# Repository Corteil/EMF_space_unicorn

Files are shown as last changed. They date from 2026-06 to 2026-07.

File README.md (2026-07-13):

# 🦄 Space Unicorn — EMF 2026 Hexpansion

A WS2812 NeoPixel hexpansion for the EMF Tildagon badge. An ATtiny85 setup as an I²C client
drives the LEDs with animated patterns, predefined colour palettes and a user
button for live pattern cycling. Settings can be saved to the ATtiny85's
internal EEPROM so the badge lights up on its own, without the control app.
This repository holds the firmware and the KiCad hardware design.

| Front | Rear |
|:-----:|:----:|
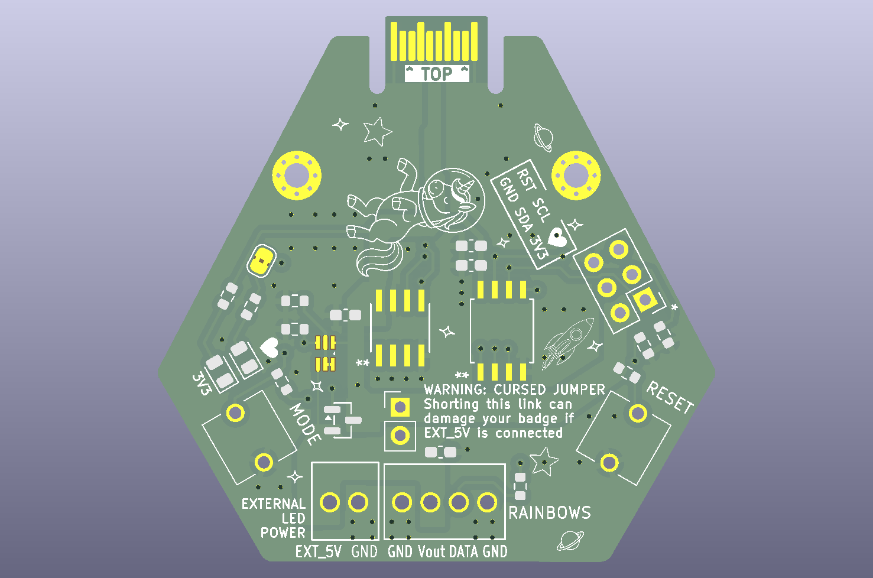
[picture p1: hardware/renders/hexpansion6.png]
Space Unicorn PCB — front
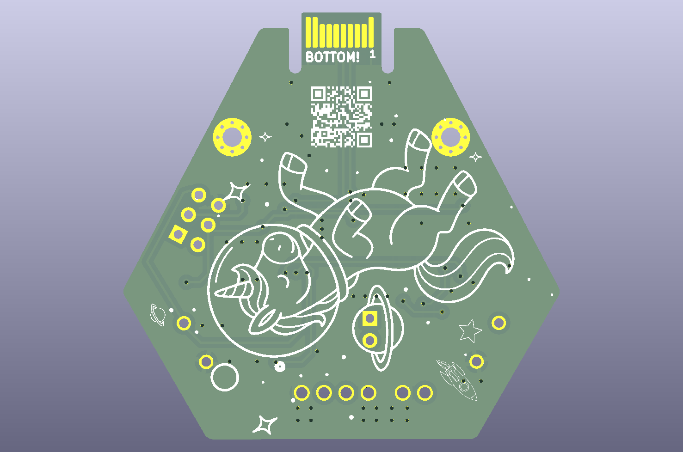
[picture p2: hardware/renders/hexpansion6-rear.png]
Space Unicorn PCB — rear
|  |  |

---

## Project links

The Space Unicorn is an EMF 2026 hexpansion — an ATtiny85 driving WS2812
NeoPixels, controlled over I²C from a Tildagon badge.

- 🦄 **Tildagon control app** — drive patterns, palettes, colour and speed from
  the badge: <https://github.com/Corteil/tildagon-space-unicorn>
- 📟 **This repo** — firmware (root) and the KiCad PCB design
  ([`hardware/`](hardware/)).
- 📇 **EMF hexpansion registry** — VID `0x1969` / PID `0x5355`, for OTA firmware:
  <https://github.com/emfcamp/hexpansion-firmwares/tree/main/0x1969/0x5355>

---

## Hardware

The full KiCad design (schematic, board, footprint libraries, gerbers and
renders) is in [`hardware/`](hardware/).

ATtiny85 pin assignments:

| Pin | Port | Function |
|-----|---|---|
| 1 | PB5/RESET| Reset button |
| 2 | PB3 | NeoPixel data output |
| 3 | PB4 | User button (active-low, internal pull-up) |
| 4 | GND | |
| 5 | PB0 | I2C SDA |
| 6 | PB1 | Heartbeat LED (1 Hz blink; flashes on I2C data)|
| 7 | PB2 | I2C SCL |
| 8 | VCC | |

### Circuit

```
                        ^ VCC
                        |
    +--------+----------+----------+-----+-------+
    |        |                     |     |       |
    |       |"| 10k                |     |       |
    |       |_|                   |"| 10k |"| 10k
    |        |   +--ATtiny85--+   |_|   |_|
    |        +---| Reset  Vcc |----+     |
    |            |            |          |
  _____ 0.1u     |        SCL |----------+-------<> SCL
  _____  ,-------| GND    SDA |------------------<> SDA
    |    |       +------------+
    |    v GND
    |
    +---------------------------------------------------> NeoPixel Data (PB3)
    |
    +--[ button ]-- GND                                   User button (PB4)
    |
    +--[ LED ]--[ 330R ]-- GND                            Heartbeat LED (PB1)
```

Pull-ups: 10 kΩ on SCL, SDA and RESET to VCC.

---

## Building

Requires `avr-gcc`, `avr-libc`, and `avrdude`.

```bash
sudo apt install gcc-avr avr-libc binutils-avr avrdude

git clone --recurse-submodules https://github.com/Corteil/EMF_space_unicorn
cd EMF_space_unicorn

make fuses  # MUST be run once on any new or replacement chip
make        # build and flash
```

The default programmer is **Atmel-ICE (ISP)**. To use a different programmer
edit the top of `Makefile`:

```makefile
AVRDUDE_PROGRAMMER = usbasp     # or linuxspi, avrisp2, usbtiny, ...
AVRDUDE_PORT       = usb
```

Build artifacts (`main.hex`, `main.elf`) are not tracked in the repository —
always build from source so the hex matches the current code.

### Fuses — required on every fresh chip

> **Important:** ATtiny85 chips ship from the factory with `CKDIV8` programmed,
> running the CPU at 1 MHz. The WS2812 driver requires exactly 8 MHz. With the
> wrong clock the NeoPixels will be **stuck solid white** and the button will be
> unresponsive.
>
> Run `make fuses` once whenever fitting a new or replacement chip. This sets
> `LFUSE=0xE2` (8 MHz internal RC, no divider) and is safe to re-run on a
> chip that is already correctly programmed.

---

## Flash and RAM usage

| Section | Used | Available |
|---|---|---|
| Flash | 3708 B  | 8192 B |
| RAM | 390 B | 512 B |

---

## I2C Protocol

**Slave address: 0x40** (hardcoded in `i2c/i2c_slave_defs.h`)

The full 8-bit register space (0x00–0xFF) is addressable.

Write transaction:

| Start | Addr (0x40) | Register | Data bytes… | Stop |

Read transaction:

| Start | Addr (0x40) | Register | Restart | Addr (0x41) | Data bytes… | Stop |

The register address auto-increments after each byte, so multi-byte reads and
writes are supported in a single transaction.

**LED values are updated only after a STOP condition is received.** There is
no per-LED frame buffer — each pixel is computed on the fly as the WS2812
stream is clocked out, so LED count is limited by power and frame rate, not
by RAM.

---

## Register Map

| Address | Name | Description | Reset |
|---|---|---|---|
| 0x00 | **CTRL** | Control register | 0x00  |
| 0x01 | **PATTERN** | Pattern ID (0–10, see table below) | 0x01  |
| 0x02 | **SPEED** | Ticks per animation frame (1=fast, 255=slow) | 0x0A  |
| 0x03 | **FALLBACK** | Pattern ID run on boot / after an idle timeout  | 0x07  |
| 0x04 | **N_LEDS_LO**  | Active LED count, low byte | 0x40  |
| 0x05 | **N_LEDS_HI**  | Active LED count, high byte | 0x00  |
| 0x06 | **N_COLS** | Matrix columns for RAINBOW_MTX (0 ⇒ 8) | 0x08  |
| 0x07 | **IDLE_TO** | Inactivity timeout in seconds before reverting to FALLBACK (0=off) | 0x00 |
| 0x08 | **PARAM1** | Pattern-specific parameter | 0x01  |
| 0x09 | **PARAM2** | Pattern-specific parameter | 0x05  |
| 0x0A | **PAL_SEL** | Palette selector (0=user, 1–7=predefined) | 0x00  |
| 0x10 | **GLB_G** | Primary colour — green | 0x00  |
| 0x11 | **GLB_R** | Primary colour — red | 0xFF  |
| 0x12 | **GLB_B** | Primary colour — blue | 0x00  |
| 0x13 | **SEC_G** | Secondary colour — green | 0x00  |
| 0x14 | **SEC_R** | Secondary colour — red | 0x00  |
| 0x15 | **SEC_B** | Secondary colour — blue | 0x00  |
| 0x20–0x4F | **PALETTE[0–15]** | 16-entry user colour palette, 3 bytes (G,R,B) each | 0x00 |
| 0x50–0xFF | **INDEX[0–351]**  | Packed 4-bit palette-index buffer for matrix mode (see below) | 0x00 |

`N_LEDS_LO`/`N_LEDS_HI` form a 16-bit active LED count (little-endian); a
value of 0 is treated as 64. `PATTERN`, `SPEED`, `PARAM1`/`PARAM2` and colours
are unchanged in meaning from earlier firmware, but have moved address.

> WS2812 byte order on the wire is **G, R, B**.

---

## CTRL Register (0x00)

| Bit | Name | Description |
|-----|---|---|
| 0 | **RST** | Write 1 to reset all registers to defaults. Auto-clears. |
| 1 | **GLB** | Write 1 to display the primary colour (GLB_G/R/B) on all LEDs. |
| 2 | **PAT_EN** | Write 1 to enable the pattern animation engine. |
| 3 | **IDX_EN** | Write 1 to stream LED colours from the packed index buffer (0x50–0xFF) instead of a pattern. |
| 4 | **SAVE** | Write 1 to persist the current configuration to EEPROM. Auto-clears once saved. |
| 7–5 | — | Reserved, read as 0. |

---

## Patterns (REG_PATTERN, 0x01)

| ID | Name | Description | Uses |
|----|---|---|---|
| 0  | OFF | All LEDs off | — |
| 1  | SOLID | All LEDs show primary colour | — |
| 2  | CHASE | Scrolling comet; tail dims by right-shift, capped at 1/128 | PARAM1 = tail length |
| 3  | BLINK | All LEDs toggle between primary and off | — |
| 4  | ALTERNATE | Even LEDs = primary, odd = secondary; swaps each frame | — |
| 5  | WIPE | Fill left→right one LED per frame, then clear | — |
| 6  | TWINKLE | Independently-timed sparkles fade in/out at random LEDs | PARAM1 = number of simultaneous sparkles (max 8) |
| 7  | RAINBOW | Full hue wheel cycling across the strip | PARAM2 = hue step per LED |
| 8  | RAINBOW_MTX | Diagonal rainbow on an N_COLS-wide grid, rotates over time | PARAM1 bit 0 = serpentine wiring |
| 9  | RETRO_BLINK | Random LEDs toggle independently (50s computer effect); state kept for the first 512 LEDs only | PARAM1 = LEDs toggled per frame (max 8) |
| 10 | LARSON | Cylon/KITT scanner; bright eye bounces end-to-end, tail dims same as CHASE | PARAM1 = tail length |

Enable a pattern by writing PAT_EN to CTRL and the ID to PATTERN. The user
button (PB4) also cycles through patterns 1–10 with a single press.

---

## Predefined Palettes (REG_PAL_SEL, 0x0A)

Writing a palette ID loads predefined primary and secondary colours from flash
(PROGMEM) into GLB and SEC registers. Writing 0 keeps the current user colours.

| ID | Name | Primary (G R B) | Secondary (G R B) |
|----|---|---|---|
| 0  | USER | *(unchanged)* | *(unchanged)* |
| 1  | FIRE | 100, 255, 0 | 0, 128, 0 |
| 2  | OCEAN | 255, 0, 255 | 0, 0, 64 |
| 3  | FOREST  | 200, 50, 0 | 48, 10, 0 |
| 4  | PARTY | 0, 255, 0 | 0, 0, 255 |
| 5  | MONO_W  | 255, 255, 255 | 32, 32, 32 |
| 6  | RAINBOW | 0, 255, 0 | 0, 0, 255 |
| 7  | HEAT | 0, 255, 0 | 200, 255, 0 |

---

## User Palette and Index Buffer (matrix mode)

Setting `CTRL_IDX_EN` switches LED output from the pattern engine to a
directly-addressable canvas, driven by two blocks:

- **`PALETTE[0–15]`** (0x20–0x4F) — 16 user-defined colours, 3 bytes (G, R, B)
  each. On reset, entries 0 and 1 are set to the primary/secondary colours;
  all 16 entries can be freely overwritten over I2C.
- **`INDEX[0–351]`** (0x50–0xFF) — one 4-bit palette index per LED, two LEDs
  packed per byte (LED *n*'s index is the low nibble of byte `n/2` if *n* is
  even, the high nibble if odd). Index **0 always renders as off/blank**,
  regardless of palette contents; indices 1–15 select `PALETTE[1]`…`PALETTE[15]`.

Index mode is bounded by the size of the index buffer: 176 bytes × 2 LEDs per
byte = **352 LEDs maximum**, irrespective of `N_LEDS`.

---

## Persistence, Fallback and Idle Timeout

- **Save**: writing `CTRL_SAVE` copies the control/colour registers and the
  16-entry user palette into the ATtiny85's internal EEPROM. The bit
  auto-clears once the save completes.
- **Boot**: on power-up, a valid saved configuration is reloaded; otherwise
  firmware defaults are used. The badge then runs the `FALLBACK` pattern
  immediately, so it lights up without the control app.
- **Idle timeout**: if `IDLE_TO` is non-zero and no I2C write is seen for that
  many seconds, the firmware reverts to the `FALLBACK` pattern.

---

## Heartbeat LED (PB1)

The LED on PB1 serves two purposes:

- **Heartbeat**: slow blink while the firmware is running, driven by Timer0 ISR.
- **Data activity**: overrides the heartbeat with a brief solid-on flash each
  time an I2C STOP condition is received.

---

## Testing

`test_registers.py` is a MicroPython / Raspberry Pi dual-platform test tool
that verifies all registers over I2C.

**Raspberry Pi (Linux):**
```bash
sudo apt install python3-smbus2
python3 test_registers.py
```

**Pi Pico (MicroPython):**
```
# Copy test_registers.py to the Pico, then run from the REPL or Thonny.
# Edit MP_PIN_SDA / MP_PIN_SCL at the top of the file to match your wiring.
mpremote run test_registers.py
```

The tool provides an interactive menu for running automated register tests and
live control of patterns, palettes, colours, and individual LEDs.

---

## Acknowledgements

This firmware extends
[neopixel_i2c](https://github.com/usedbytes/neopixel_i2c) by
**Brian Starkey (usedbytes)**, which provides the USI I2C slave implementation
and the original WS2812 driving code. The WinAVR Makefile was written by
**Eric B. Weddington, Jörg Wunsch et al.** and modified by **Elliot Williams**.
The [light_ws2812](https://github.com/cpldcpu/light_ws2812) library by
**cpldcpu** is used for WS2812 output.

---

---

# Original README — neopixel_i2c (picopixel)

> The following is the original README from the upstream neopixel_i2c project
> by Brian Starkey (usedbytes), preserved for reference.

This is an AVR-based neopixel driver. It accepts commands over i2c to drive a
a number of ws2812 LED pixels.

The code on the master branch is set up for an Attiny85, with the LEDs on PB3,
using an usbasp programmer. The fuses should be set to use 8 MHz internal
oscillator, **no divider**

## How many LEDs?
The number of LEDs is currently hardcoded in the firmware. The maximum number
depends on the amount of RAM available on your AVR.
An Attiny45 should be able to drive 82 LEDs, and an Attiny85, 167.

## Circuit

Suggested circuit.

```
                            ^ VCC
                            |
    +--------+--------------+-------------+-----+-------+
    |        |                            |     |       |
    |       |"| 10k                       |     |       |
    |       |_|                           |     |       |
    |        |     +Attinyx5--------+     |    |"| 2k2 |"| 2k2
    |        +-----| Reset      Vcc |-----'    |_|     |_|
    |              |                |           |       |
  _____ 0.1u       |                |           |       |
  _____  ,---------|            SCL |-----------+-------|-----<> SCL
    |    |         |                |                   |
    |    |         |                |                   |
    |    |       --|                |--                 |
    |    |         |                |                   |
    |    |         |                |                   |
    +----|---+-----| GND        SDA |-------------------+-----<> SDA
         |   |     +----------------+
         |   v GND
         |
         '-----------------------------------------------------> NeoPixel Data

```

## Getting the code

This project uses git submodules (I kinda wish it didn't...). You can clone
it like so:

```git clone --recursive https://github.com/usedbytes/neopixel_i2c```

If your git version is too old to support that, do this instead:

```
git clone --recursive https://github.com/usedbytes/neopixel_i2c
cd neopixel_i2c
git submodule update --init --recursive
```

## Basic Functionality

There are two basic operating modes:
 * In *normal* mode, each LED is individually driven based on the value in its
   control register.
 * In *global* mode, all LEDs are driven to the same value, based on the values
   in the global value registers.

The operating modes are selected by flipping the *GLB* bit in the **CTRL**
register.

## i2c Protocol

**The slave address is currently hardcoded to 0x40 in the firmware**, see

```
i2c/i2c_slave_defs.h:30
```

This utilises my i2c slave library (https://github.com/usedbytes/usi_i2c_slave)
which means it follows a fairly standard i2c protocol (for more, see here:
http://www.robot-electronics.co.uk/i2c-tutorial).

Writes look like this:

| Start | Slave Address << 1 | Register Address | Data | Stop |
|-------|--------------------|------------------|------|------|

The register address will auto-increment after every byte, so you can write
data in bursts.

Reads look like this:

| Start | Slave Address | Register Address | Restart | (Slave Address << 1) + 1  | Data | Stop |
|-------|---------------|------------------|---------|---------------------------|------|------|

First you do a write transaction to set the register address to read from, then
a read transaction to read the data. When you've read all the data you want,
send a NAK after the last byte to terminate the read.

**The LED values are only updated after a STOP is received**

## Register Map
The register map consists of a number of global control registers - address
0x0-0x3 - followed by an array of registers which hold the individual value
for each LED in normal mode.

| **Address** | **Name**     | **Description**      | **Access** | **Reset** |
|------------:|--------------|:---------------------|--------|------:|
|   0x00      | **CTRL**     | Control Register     | R/W    |    0  |
|   0x01      | **GLB_G**    | Global Green Value   | R/W    |    0  |
|   0x02      | **GLB_R**    | Global Red Value     | R/W    |    0  |
|   0x03      | **GLB_B**    | Global Blue Value    | R/W    |    0  |
|Array follows|--------------|----------------------|--------|-------|
|   0x04      | **GREEN[0]** | Green value, LED0    | R/W    |    0  |
|   0x05      | **RED[0]**   | Red value, LED0      | R/W    |    0  |
|   0x06      | **BLUE[0]**  | Blue value, LED0     | R/W    |    0  |
|   ....      | ....         | ....                 | ....   | ....  |
| (3*n) + 4   | **GREEN[n]** | Green value, LEDn    | R/W    |    0  |
| (3*n) + 5   | **RED[n]**   | Red value, LEDn      | R/W    |    0  |
| (3*n) + 6   | **BLUE[n]**  | Blue value, LEDn     | R/W    |    0  |

## Register Descriptions

### **CTRL**
The control register sets the operating mode.

|   Name: | RSVD | RSVD | RSVD | RSVD | RSVD | RSVD | GLB  | RST  |
|--------:|:----:|:----:|:----:|:----:|:----:|:----:|:----:|:----:|
|    Bit: |    7 |    6 |    5 |    4 |    3 |    2 |    1 |    0 |
| Access: |    r |    r |   r  |   r  |   r  |   r  |  rw  |  rw  |

#### *RST*
Writing a 1 to this bit will reset the LED controler, setting all LEDs to OFF

This bit will be automatically cleared once the reset has completed.

#### *GLB*
Writing a one to this bit causes the global color value to be displayed on all
LEDs at the end of the transaction - Normally you would set the **GLB_R**,
**GLB_G**, and **GLB_B** values in the same transaction as setting the *GLB*
bit so that the new colour is immediately applied.

Writing a zero to this bit will disable the global colour override and return to
normal operation.

### **GLB_R**, **GLB_G**, **GLB_B**
These registers hold the global colour value. When the *GLB* bit in the
**CTRL** register is set, all LEDs will display this colour.

### **LED Value Array**
Everything after the global registers is an array of data for each LED.
When the *GLB* bit is not set, each LED will display whatever value is
programmed in its corresponding register set.

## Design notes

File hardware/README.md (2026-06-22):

# Space Unicorn — hardware

KiCad design files for the EMF26 Space Unicorn hexpansion.

| Front | Rear |
|:-----:|:----:|
| Space Unicorn PCB — front | Space Unicorn PCB — rear |

## Contents

| Path | What |
|---|---|
| `hexpansion.kicad_pro` / `.kicad_sch` / `.kicad_pcb` | KiCad project, schematic and board. |
| `fp-lib-table`, `sym-lib-table` | Library tables. |
| `*.pretty/` | Project-local footprint libraries (`unicorn`, `heart`, `gfx`, `NextPCB`). |
| `gerbers/` | Gerbers + drill files for fabrication. |
| `renders/` | Board renders and the paper template. |
| `LICENSE.txt` | Hardware licence. |

## Notes

- The board carries an **ATtiny85** (WS2812 driver, I²C `0x40`), an **M24256E**
  EEPROM (hexpansion identity + resident app), and a **BC857BS** for Ext_5V
  reverse-feed protection.
- `fp-lib-table` references some footprints by absolute local paths (parts from
  `…/Hardware/parts/…`) and a sibling `tildagon-base`. These won't resolve on a
  fresh clone, but KiCad **caches footprints in the `.kicad_pcb`**, so the board
  opens, views and plots correctly. Re-point those library entries if you need to
  edit footprints.

## Related

- Firmware: this repository's root.
- Tildagon control app: <https://github.com/Corteil/tildagon-space-unicorn>

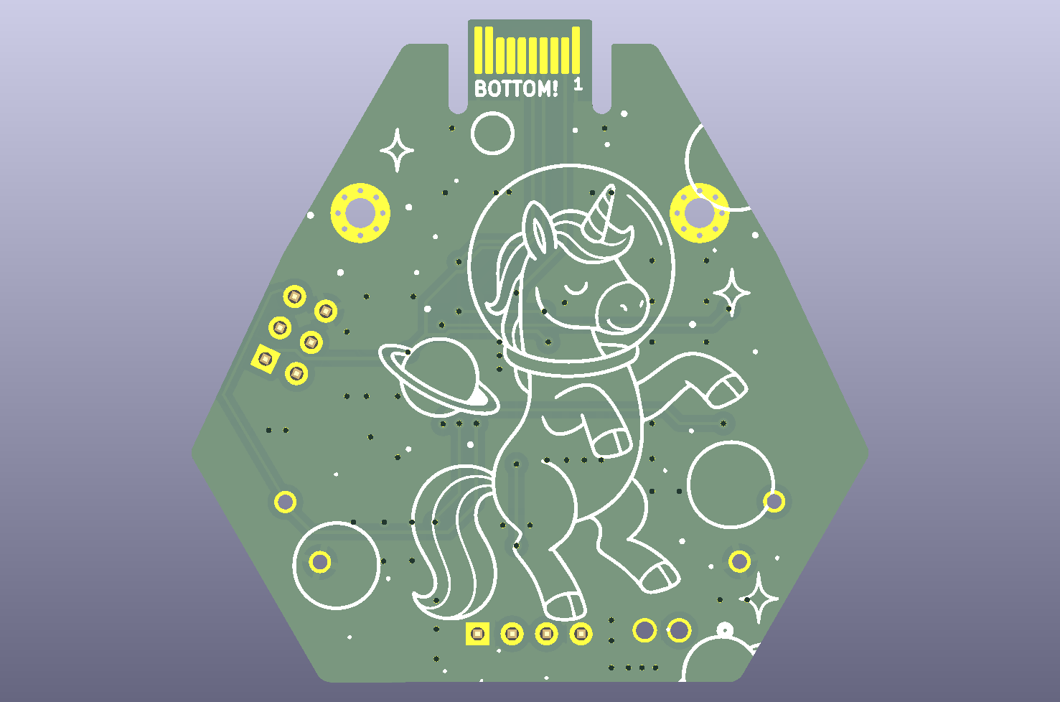
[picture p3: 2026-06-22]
hardware/renders/hexpansion-V3-back.png

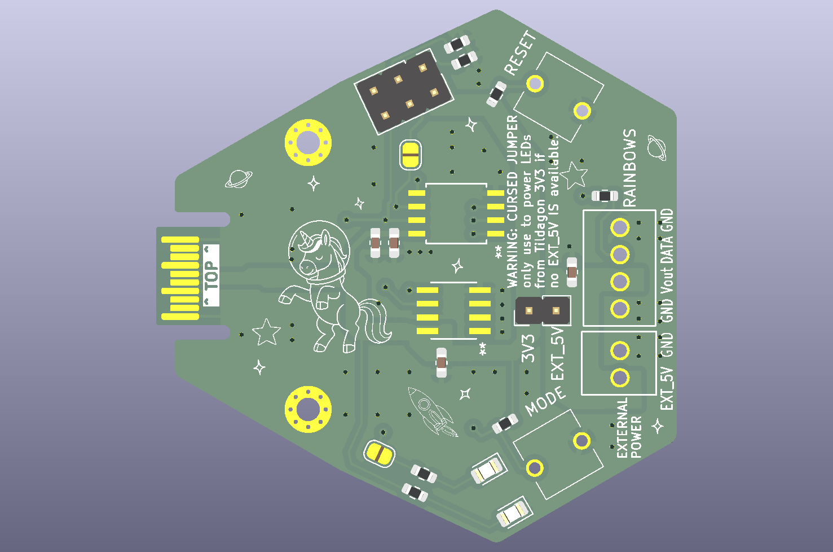
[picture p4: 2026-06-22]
hardware/renders/hexpansion-V4.png

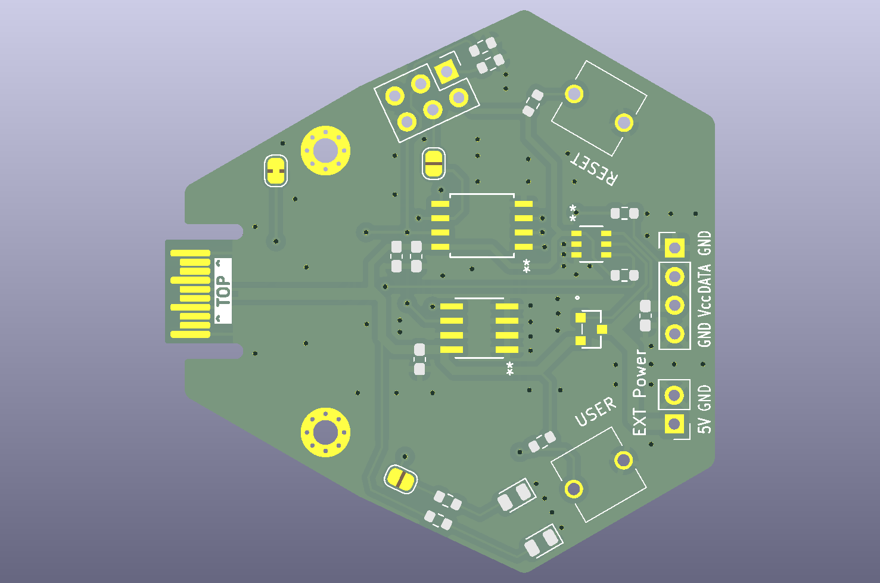
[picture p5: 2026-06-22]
hardware/renders/hexpansion-V1.png

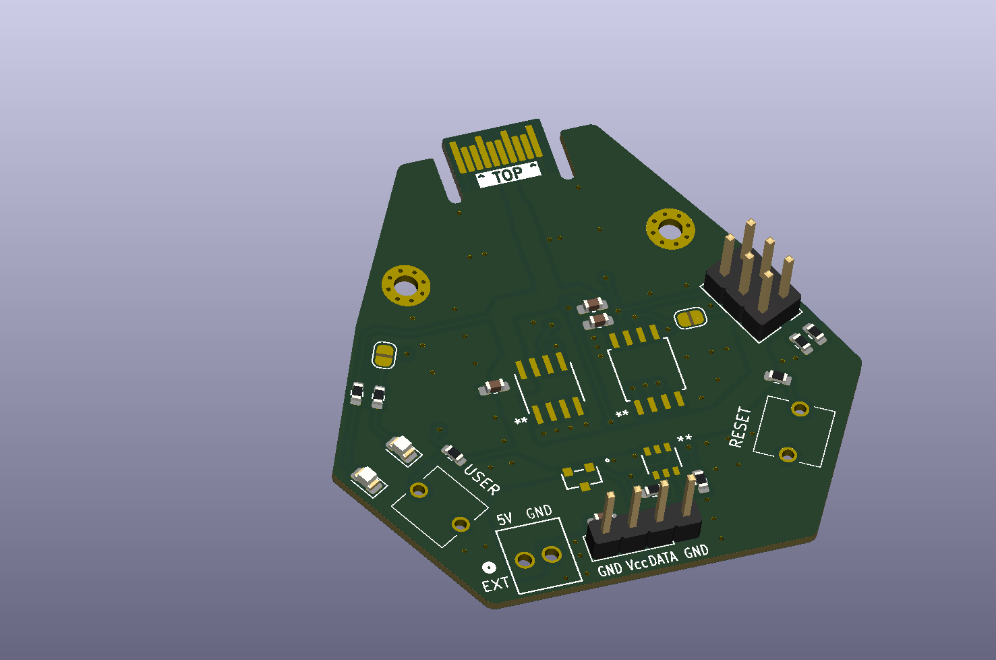
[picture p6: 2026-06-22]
hardware/renders/hexpansion-V2.png

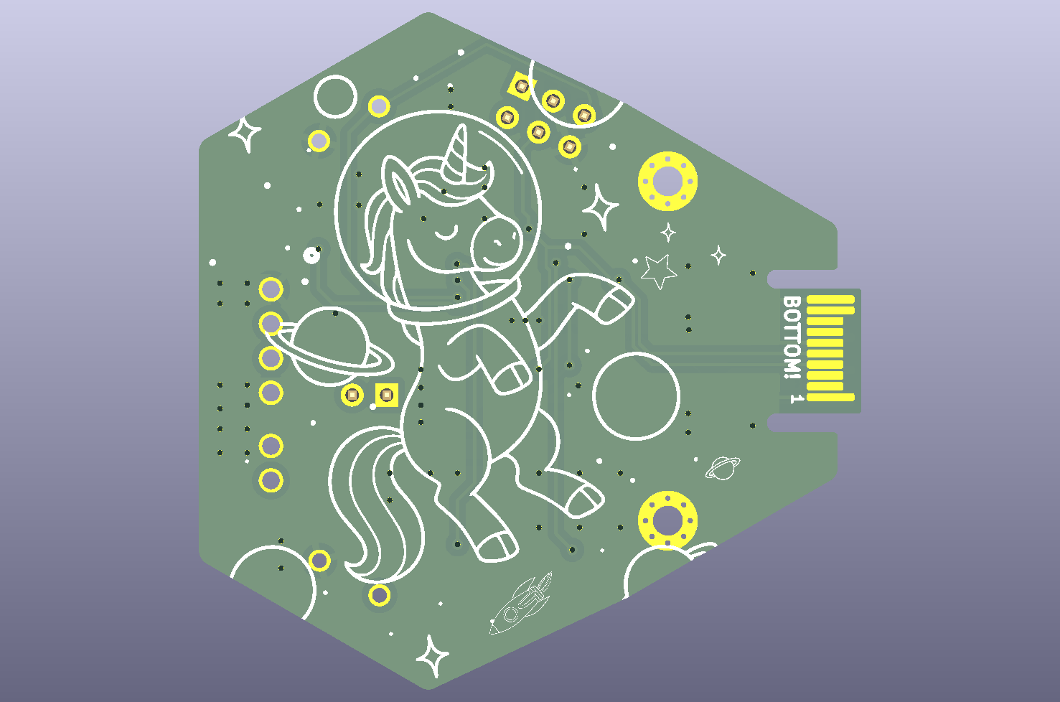
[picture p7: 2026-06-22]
hardware/renders/hexpansion-V4-rear.png

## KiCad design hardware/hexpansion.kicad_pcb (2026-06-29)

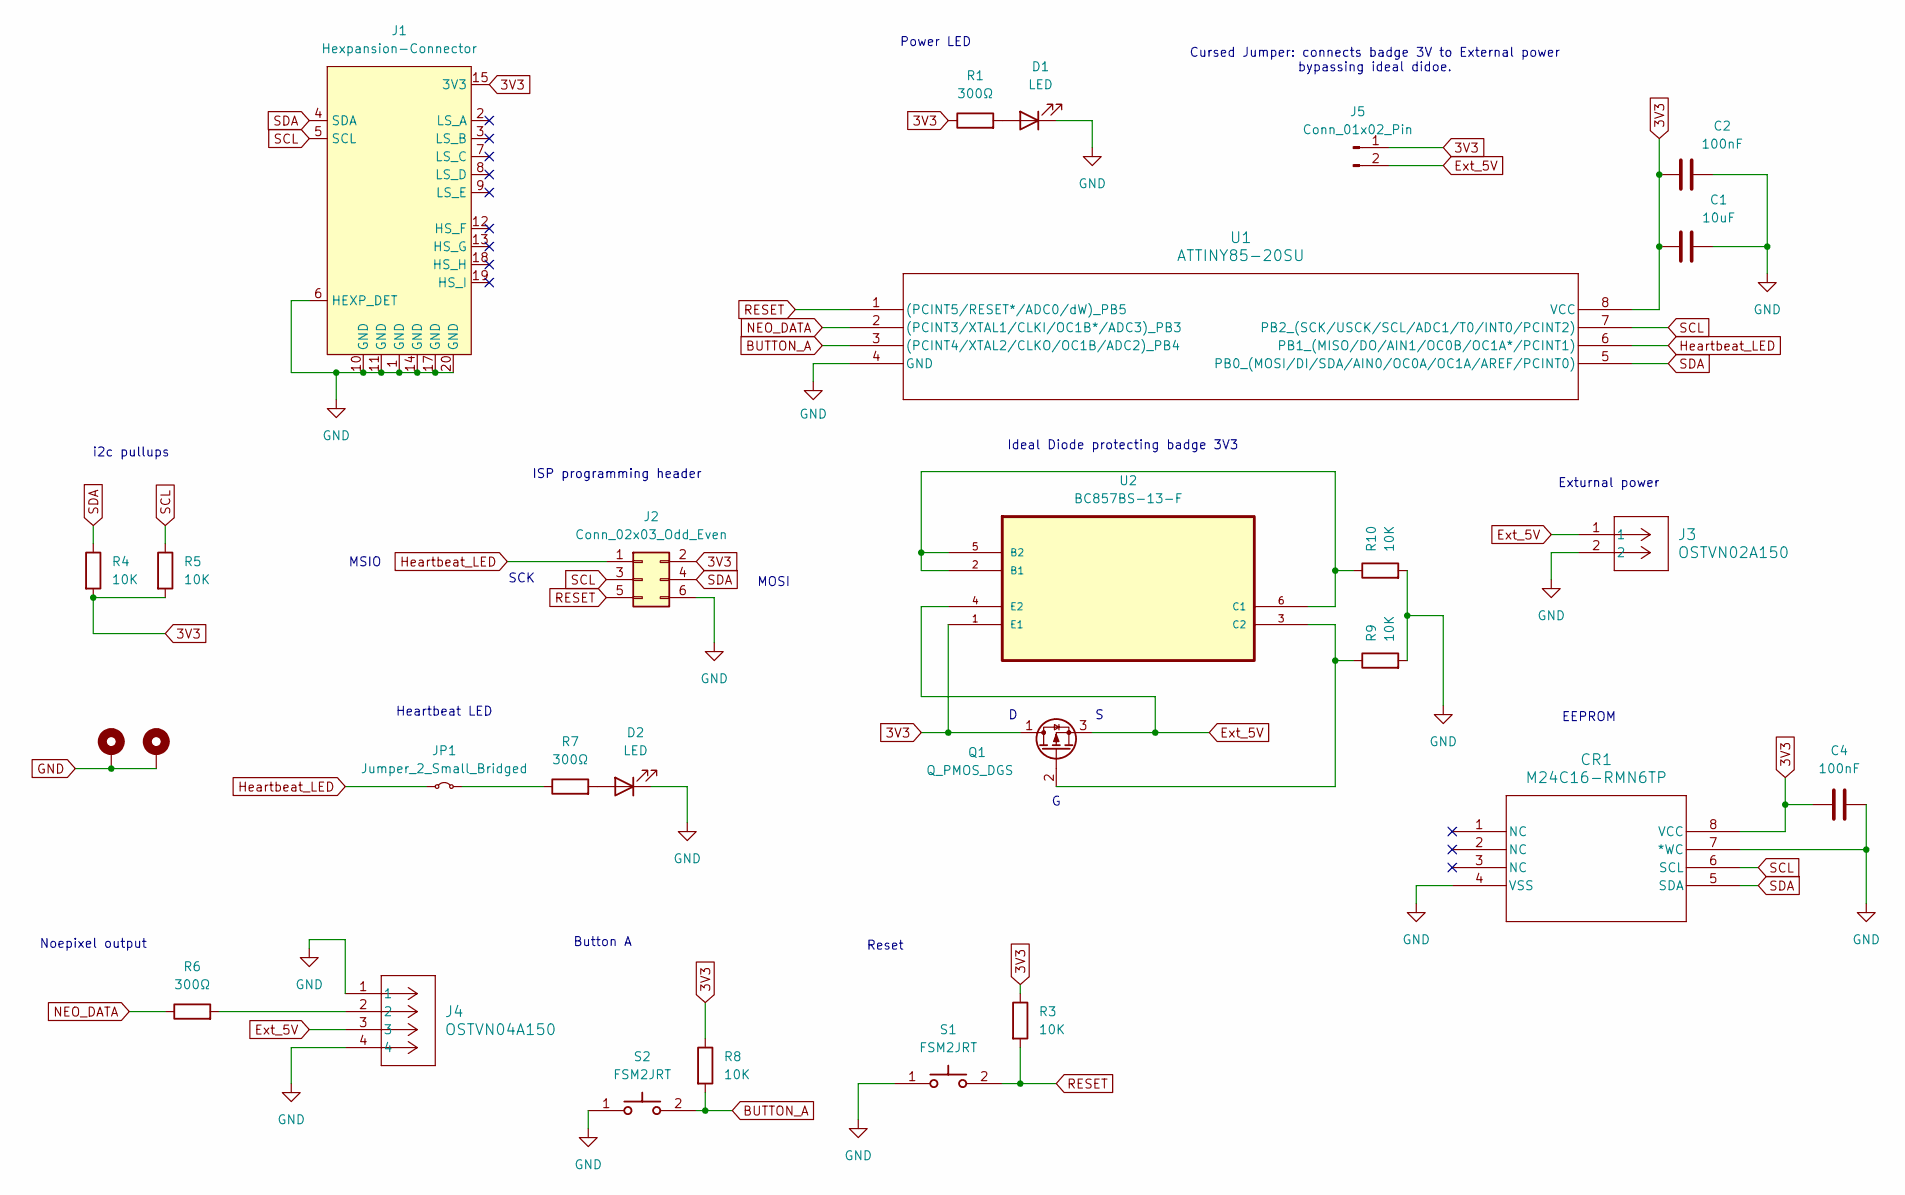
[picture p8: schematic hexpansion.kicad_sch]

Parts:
C1: 10uF; C_0603_1608Metric_Pad1.08x0.95mm_HandSolder
C2, C4: 100nF; C_0603_1608Metric_Pad1.08x0.95mm_HandSolder
CR1: M24C16-RMN6TP; SO-8_STM
D1, D2: LED; LED_0805_2012Metric
H1, H2: MountingHole_Pad; MountingHole_2.2mm_M2_Pad_Via
J1: Hexpansion-Connector; hexpansion-edge-connector
J2: Conn_02x03_Odd_Even; PinHeader_2x03_P2.54mm_Vertical
J3: OSTVN02A150; CONN_OSTVN02A150_OST
J4: OSTVN04A150; CONN_OSTVN04A150_OST
J5: Conn_01x02_Pin; PinHeader_1x02_P2.54mm_Vertical
JP1: Jumper_2_Small_Bridged; SolderJumper-2_P1.3mm_Bridged2Bar_RoundedPad1.0x1.5mm
Q1: Q_PMOS_DGS; SOT-23
R1, R6, R7: 300Ω; R_0603_1608Metric
R3, R4, R5, R8, R9, R10: 10K; R_0603_1608Metric
S1, S2: FSM2JRT; Manufacturer_Part_Number FSM2JRT
U1: ATTINY85-20SU; 8S2_ATM
U2: BC857BS-13-F; SOT65P210X100-6N; MPN BC857BS-13-F

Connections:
3V3: C1.1, C2.1, C4.1, CR1.8 (VCC), J1.15 (3V3), J1.16 (3V3), J2.2, J5.1, Q1.1 (D), R1.1, R3.1, R4.2, R5.2, R8.1, U1.8 (VCC), U2.1 (E1)
BUTTON_A: R8.2, S2.2 (NO), U1.3 ((PCINT4/XTAL2/CLKO/OC1B/ADC2)_PB4)
Ext_5V: J3.1, J4.3, J5.2, Q1.3 (S), U2.4 (E2); also elsewhere on the board
GND: C1.2, C2.2, C4.2, CR1.4 (VSS), CR1.7 (*WC), D1.1 (K), D2.1 (K), H1.1 (1_1), H2.1 (1_1), J1.1 (GND), J1.6 (HEXP_DET), J1.10 (GND), J1.11 (GND), J1.14 (GND), J1.17 (GND), J1.20 (GND), J2.6, J3.2, J4.1, J4.4, R9.2, R10.2, S1.1 (COM), S2.1 (COM), U1.4 (GND); also elsewhere on the board
Heartbeat_LED: J2.1, JP1.1 (A), U1.6 (PB1_(MISO/DO/AIN1/OC0B/OC1A*/PCINT1))
NEO_DATA: R6.1, U1.2 ((PCINT3/XTAL1/CLKI/OC1B*/ADC3)_PB3)
unnamed: D1.2 (A), R1.2
unnamed: D2.2 (A), R7.2
unnamed: J4.2, R6.2
unnamed: JP1.2 (B), R7.1
unnamed: Q1.2 (G), R9.1, U2.3 (C2)
unnamed: R10.1, U2.2 (B1), U2.5 (B2), U2.6 (C1)
RESET: J2.5, R3.2, S1.2 (NO), U1.1 ((PCINT5/RESET*/ADC0/dW)_PB5)
SCL: CR1.6 (SCL), J1.5 (SCL), J2.3, R5.1, U1.7 (PB2_(SCK/USCK/SCL/ADC1/T0/INT0/PCINT2))
SDA: CR1.5 (SDA), J1.4 (SDA), J2.4, R4.1, U1.5 (PB0_(MOSI/DI/SDA/AIN0/OC0A/OC1A/AREF/PC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)

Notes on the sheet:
Power LED
Exturnal power
Heartbeat LED
Noepixel output
MSIO
EEPROM
MOSI
ISP programming header
SCK
Reset
Button A
Cursed Jumper: connects badge 3V to External power bypassing ideal didoe.
Ideal Diode protecting badge 3V3
i2c pullups

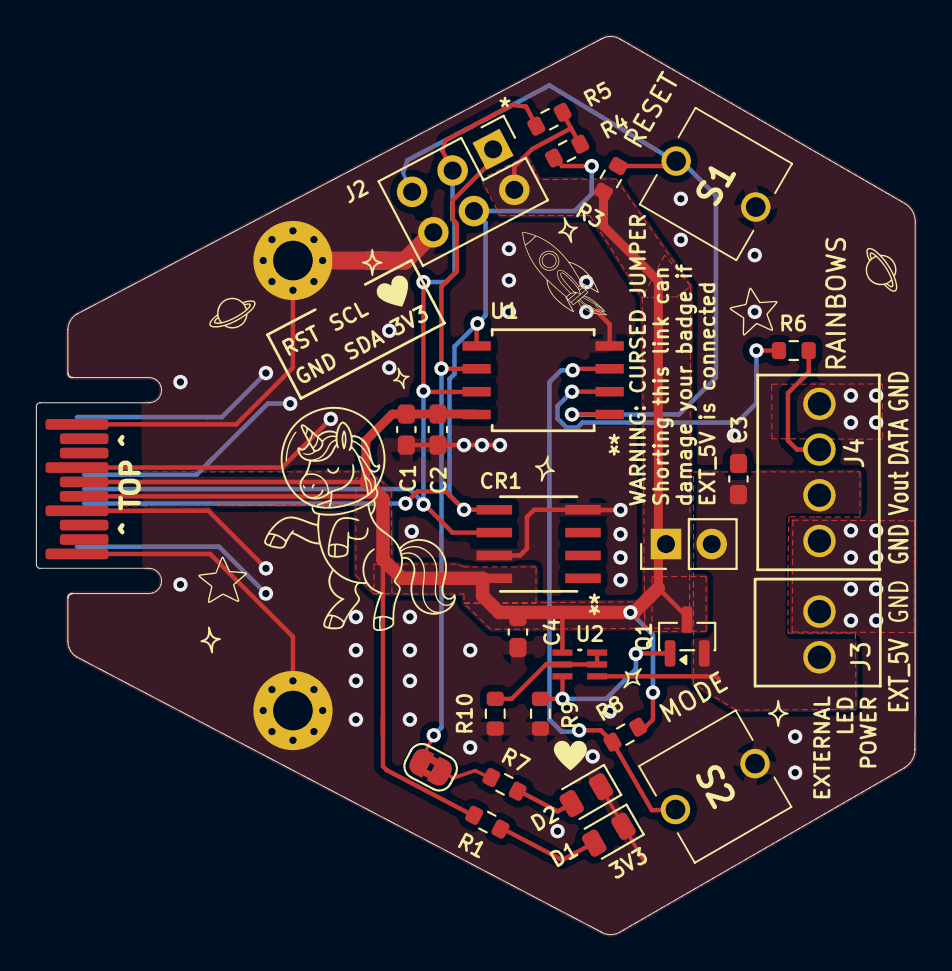
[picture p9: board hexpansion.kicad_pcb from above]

Board: 2 copper layers, 48.8 x 49.9 mm, 29 parts (0 on the bottom side), 15 nets.

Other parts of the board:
C3: 100nF; C_0603_1608Metric_Pad1.08x0.95mm_HandSolder

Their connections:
Ext_5V: C3.1; also elsewhere on the board
GND: C3.2; also elsewhere on the board

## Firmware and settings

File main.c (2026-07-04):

/*
 * NeoPixel I2C Slave — Space Unicorn firmware v2 (buffer-free streaming)
 *
 * Pin map (ATtiny85):
 *   PB0 (pin 5) : I2C SDA
 *   PB1 (pin 6) : Heartbeat LED  (slow blink = alive; brief flash = I2C data)
 *   PB2 (pin 7) : I2C SCL
 *   PB3 (pin 2) : NeoPixel data
 *   PB4 (pin 3) : User button    (active-low, internal pull-up)
 *   PB5 (pin 1) : RESET
 *
 * There is no per-LED RGB frame buffer. Each pixel's colour is computed on the
 * fly (see patterns.c) as the WS2812 signal is clocked out, so the number of
 * LEDs is limited by power and frame rate, not by the ATtiny85's 512 bytes of
 * RAM. See i2c/i2c_slave_defs.h for the register map.
 *
 * Persistence:
 *   - Writing CTRL_SAVE stores the current configuration to the ATtiny85's
 *     internal EEPROM.
 *   - On power-on the saved configuration is reloaded (or firmware defaults if
 *     none), and the REG_FALLBACK pattern runs so the badge lights up without
 *     needing the control app.
 *   - If no I2C write is seen for REG_IDLE_TO seconds, the firmware reverts to
 *     the REG_FALLBACK pattern.
 */

#include <util/delay.h>
#include <avr/io.h>
#include <avr/interrupt.h>
#include <avr/pgmspace.h>
#include <avr/eeprom.h>
#include <Light_WS2812/light_ws2812.h>
#include <i2c/i2c_slave_defs.h>
#include <i2c/i2c_machine.h>
#include "patterns.h"

#define PIN_NEOPIXEL  PB3
#define PIN_HB_LED    PB1
#define PIN_BUTTON    PB4

/* Default primary colour in WS2812 G/R/B order: pure red */
static const uint8_t init_color[3] PROGMEM = { 0x00, 0xFF, 0x00 };

/* Default 16-colour user palette, G/R/B per entry. Slots 0/1 are overwritten
 * with the primary/secondary colours by do_reset(). */
static const uint8_t default_palette[PAL_ENTRIES][3] PROGMEM = {
    { 255, 255, 255 }, {   0,   0,   0 }, {   0, 255,   0 }, { 255,   0,   0 },
    {   0,   0, 255 }, { 255, 255,   0 }, { 255,   0, 255 }, {   0, 255, 255 },
    { 128, 255,   0 }, {   0, 128, 255 }, { 255,   0, 128 }, {   0, 255, 128 },
    {  64,  64,  64 }, { 128, 128, 128 }, { 192, 192, 192 }, { 200, 255, 100 },
};

volatile uint8_t i2c_reg[I2C_N_REG];

static struct pat_state pat;
static uint8_t  last_pal_sel;
static uint8_t  last_pattern;
static uint8_t  dirty;              /* a fresh frame needs streaming */

/* Set by Timer0 at ~30 Hz; drives animation timing and the inactivity counter */
static volatile uint8_t  tick_flag;
static volatile uint16_t idle_ticks;
static volatile uint8_t  flash_timer;
static volatile uint8_t  btn_event;

/* ------------------------------------------------------------------ */
/* EEPROM persistence                                                   */
/* ------------------------------------------------------------------ */

#define EE_MAGIC_ADDR 0
#define EE_MAGIC_VAL  0x5E
/* Config block: 0x01..0x11 mirrors the control/colour registers */
#define EE_CFG_BASE   1     /* PATTERN,SPEED,FALLBACK,NLEDS_LO,NLEDS_HI,NCOLS,
                             * IDLE_TO,PARAM1,PARAM2,PAL_SEL,GLB_G,GLB_R,GLB_B,
                             * SEC_G,SEC_R,SEC_B  (16 bytes) */
#define EE_CFG_LEN    16
#define EE_PAL_BASE   (EE_CFG_BASE + EE_CFG_LEN)   /* 17: 48 palette bytes */

static const uint8_t cfg_regs[EE_CFG_LEN] = {
    0x01, 0x02, 0x03, 0x04, 0x05, 0x06, 0x07, 0x08, 0x09, 0x0A,
    0x10, 0x11, 0x12, 0x13, 0x14, 0x15,
};

static void save_state(void)
{
    uint8_t i;
    for (i = 0; i < EE_CFG_LEN; i++)
        eeprom_update_byte((uint8_t *)(EE_CFG_BASE + i), i2c_reg[cfg_regs[i]]);
    for (i = 0; i < PAL_ENTRIES * 3; i++)
        eeprom_update_byte((uint8_t *)(EE_PAL_BASE + i), i2c_reg[PAL_BASE + i]);
    eeprom_update_byte((uint8_t *)EE_MAGIC_ADDR, EE_MAGIC_VAL);   /* validate last */
}

/* Returns non-zero if a valid saved configuration was loaded. */
static uint8_t load_state(void)
{
    uint8_t i;
    if (eeprom_read_byte((uint8_t *)EE_MAGIC_ADDR) != EE_MAGIC_VAL)
        return 0;
    for (i = 0; i < EE_CFG_LEN; i++)
        i2c_reg[cfg_regs[i]] = eeprom_read_byte((uint8_t *)(EE_CFG_BASE + i));
    for (i = 0; i < PAL_ENTRIES * 3; i++)
        i2c_reg[PAL_BASE + i] = eeprom_read_byte((uint8_t *)(EE_PAL_BASE + i));
    return 1;
}

/* ------------------------------------------------------------------ */
/* Timer0 ISR — heartbeat, button debounce, animation + idle timing     */
/* ------------------------------------------------------------------ */

ISR(TIMER0_OVF_vect)
{
    static uint8_t hb_div   = 0;
    static uint8_t btn_cnt  = 0;
    static uint8_t btn_held = 0;

    tick_flag = 1;
    if (idle_ticks < 0xFFFF)
        idle_ticks++;

    if (flash_timer) {
        flash_timer--;
        PORTB |= (1 << PIN_HB_LED);
    } else if (++hb_div >= 15) {
        hb_div = 0;
        PORTB ^= (1 << PIN_HB_LED);
    }

    /* User button — active low */
    if (!(PINB & (1 << PIN_BUTTON))) {
        if (btn_cnt < 255) btn_cnt++;
        if (btn_cnt == 3 && !btn_held) {
            btn_held  = 1;
            btn_event = 1;
        }
    } else {
        btn_cnt  = 0;
        btn_held = 0;
    }
}

static inline void hb_flash(void) { flash_timer = 6; }

/* ------------------------------------------------------------------ */
/* Configuration helpers                                                */
/* ------------------------------------------------------------------ */

static void init_default_palette(void)
{
    uint8_t i;
    for (i = 0; i < PAL_ENTRIES * 3; i++)
        i2c_reg[PAL_BASE + i] = pgm_read_byte(&default_palette[0][0] + i);
}

static void do_reset(void)
{
    REG_CTRL      = 0;
    REG_PATTERN   = PAT_SOLID;
    REG_SPEED     = 10;
    REG_FALLBACK  = PAT_RAINBOW;
    REG_N_LEDS_LO = 64;
    REG_N_LEDS_HI = 0;
    REG_N_COLS    = 8;
    REG_IDLE_TO   = 0;
    REG_PARAM1    = 1;
    REG_PARAM2    = 5;
    REG_PAL_SEL   = 0;

    REG_GLB_G = pgm_read_byte(init_color);
    REG_GLB_R = pgm_read_byte(init_color + 1);
    REG_GLB_B = pgm_read_byte(init_color + 2);
    REG_SEC_G = 0; REG_SEC_R = 0; REG_SEC_B = 0;

    init_default_palette();
    /* Slots 0 and 1 alias the primary / secondary colours */
    i2c_reg[PAL_BASE + 0] = REG_GLB_G;
    i2c_reg[PAL_BASE + 1] = REG_GLB_R;
    i2c_reg[PAL_BASE + 2] = REG_GLB_B;
    i2c_reg[PAL_BASE + 3] = REG_SEC_G;
    i2c_reg[PAL_BASE + 4] = REG_SEC_R;
    i2c_reg[PAL_BASE + 5] = REG_SEC_B;

    last_pal_sel = 0;
    pat_init(&pat);
}

static void apply_fallback(void)
{
    REG_PATTERN  = REG_FALLBACK;
    REG_CTRL     = CTRL_PAT_EN;
    last_pattern = REG_PATTERN;
    pat_init(&pat);
    dirty = 1;
}

/* ------------------------------------------------------------------ */
/* Buffer-free frame streaming                                          */
/* ------------------------------------------------------------------ */

static inline uint16_t active_n_leds(void)
{
    uint16_t n = ((uint16_t)REG_N_LEDS_HI << 8) | REG_N_LEDS_LO;
    return n ? n : 64;
}

static void stream_frame(void)
{
    uint16_t n = active_n_leds();
    uint16_t i;
    uint8_t  sreg;

    if (REG_CTRL & CTRL_IDX_EN) {
        /* Index mode is bounded by the size of the packed index buffer */
        if (n > (uint16_t)(IDX_BYTES * 2))
            n = IDX_BYTES * 2;
    } else {
        pat_prep(&pat, n);
    }

    /* Interrupts off for the whole frame: the WS2812 stream must not be
     * interrupted, and ws2812_sendarray() restores SREG (so it will not
     * re-enable interrupts while we hold them off). */
    sreg = SREG;
    cli();

    for (i = 0; i < n; i++) {
        struct cRGB px;
        if (REG_CTRL & CTRL_IDX_EN) {
            uint8_t byte = i2c_reg[IDX_BASE + (i >> 1)];
            uint8_t idx  = (i & 1) ? (byte >> 4) : (byte & 0x0F);
            if (idx == 0) {
                /* Index 0 = blank/off, so an unpainted matrix reads as an empty
                 * canvas that matches the editor's blank cells. */
                px.g = 0; px.r = 0; px.b = 0;
            } else {
                uint8_t base = PAL_BASE + idx + (idx << 1);   /* PAL_BASE + idx*3 */
                px.g = i2c_reg[base];
                px.r = i2c_reg[base + 1];
                px.b = i2c_reg[base + 2];
            }
        } else {
            compute_led(&pat, i, n, &px);
        }
        ws2812_sendarray((uint8_t *)&px, 3);
    }

    SREG = sreg;
    _delay_us(50);   /* latch */
}

/* ------------------------------------------------------------------ */
/* Main                                                                 */
/* ------------------------------------------------------------------ */

int main(void)
{
    DDRB  = (1 << PIN_NEOPIXEL) | (1 << PIN_HB_LED);
    PORTB = (1 << PIN_BUTTON);

    /* Timer0 overflow at 8 MHz / 1024 / 256 ≈ 30 Hz */
    TCCR0B = (1 << CS02) | (1 << CS00);
    TIMSK |= (1 << TOIE0);

    if (!load_state())
        do_reset();

    apply_fallback();      /* power on into the fallback effect */

    i2c_init();
    sei();

    for (;;) {
        uint8_t changed = i2c_check_stop();

        if (changed) {
            idle_ticks = 0;
            hb_flash();

            if (REG_CTRL & CTRL_RST) {
                do_reset();
                apply_fallback();
            } else {
                if (REG_CTRL & CTRL_SAVE) {
                    save_state();
                    REG_CTRL &= ~CTRL_SAVE;    /* acknowledge the save */
                }
                if (REG_PAL_SEL != last_pal_sel) {
                    load_palette(REG_PAL_SEL);
                    last_pal_sel = REG_PAL_SEL;
                }
                if (REG_PATTERN != last_pattern) {
                    last_pattern = REG_PATTERN;
                    pat_init(&pat);
                }
            }
            dirty = 1;
        }

        /* User button: cycle to the next pattern */
        if (btn_event) {
            btn_event = 0;
            uint8_t next = REG_PATTERN + 1;
            if (next > PAT_MAX) next = PAT_SOLID;
            REG_PATTERN  = next;
            REG_CTRL     = CTRL_PAT_EN;
            last_pattern = next;
            pat_init(&pat);
            idle_ticks = 0;
            dirty = 1;
        }

        /* Inactivity fallback */
        if (REG_IDLE_TO) {
            uint16_t ticks;
            cli(); ticks = idle_ticks; sei();
            if (ticks >= (uint16_t)REG_IDLE_TO * 30) {
                apply_fallback();
                cli(); idle_ticks = 0; sei();
            }
        }

        /* Advance the animation at ~30 Hz, subdivided by REG_SPEED */
        if (tick_flag) {
            tick_flag = 0;
            if (REG_CTRL & CTRL_PAT_EN) {
                if (pat_tick(&pat, active_n_leds()) && pat_is_animated(REG_PATTERN))
                    dirty = 1;
            }
        }

        if (dirty) {
            stream_frame();
            dirty = 0;
        }
    }
}

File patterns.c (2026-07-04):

#include <avr/pgmspace.h>
#include <i2c/i2c_slave_defs.h>
#include "patterns.h"

extern volatile uint8_t i2c_reg[];

/*
 * Buffer-free pattern engine.
 *
 * There is no per-LED frame buffer: compute_led() produces each pixel's colour
 * on demand as the WS2812 stream is clocked out. Patterns that would otherwise
 * need a multiply or divide per pixel (rainbow hue = i * step, matrix row/col =
 * i / cols) instead advance a running accumulator, which works because LEDs are
 * always streamed in ascending index order. The ATtiny85 has no hardware
 * multiplier, so this keeps the inner loop short enough to avoid a WS2812 latch.
 */

/*
 * Predefined palettes stored in flash: {pri_G, pri_R, pri_B, sec_G, sec_R, sec_B}
 * WS2812 byte order is G, R, B.
 */
static const uint8_t predefined_palettes[7][6] PROGMEM = {
    /* 1 FIRE    */ { 100, 255,   0,   0, 128,   0 },
    /* 2 OCEAN   */ { 255,   0, 255,   0,   0,  64 },
    /* 3 FOREST  */ { 200,  50,   0,  48,  10,   0 },
    /* 4 PARTY   */ {   0, 255,   0,   0,   0, 255 },
    /* 5 MONO_W  */ { 255, 255, 255,  32,  32,  32 },
    /* 6 RAINBOW */ {   0, 255,   0,   0,   0, 255 },
    /* 7 HEAT    */ {   0, 255,   0, 200, 255,   0 },
};

/* Per-frame constants, recomputed once by pat_prep() then read by compute_led() */
static uint16_t s_head;        /* chase comet head */
static uint16_t s_eye;         /* larson eye position */
static uint16_t s_wpos;        /* wipe fill/clear position */
static uint8_t  s_hue;         /* rainbow running hue (advances per LED) */
static uint8_t  s_col;         /* matrix column accumulator */
static uint8_t  s_row;         /* matrix row accumulator */
static uint8_t  s_phase;       /* blink/alternate parity */

/*
 * Retro Blink and Twinkle need genuine per-LED memory to look randomly
 * time-varying rather than a fixed function of index — a small, deliberate
 * exception to the buffer-free design above.
 *
 * Retro Blink: one persistent on/off bit per LED (like an old blinkenlights
 * panel), capped to BLINK_MAX_LEDS so it stays cheap; PARAM1 bits flip per
 * frame advance. LEDs beyond the cap stay off.
 *
 * Twinkle: a small set of independently-timed "sparkle" slots, each holding
 * a target LED index and a fade level; when a slot's fade reaches zero it is
 * reseeded to a new random LED anywhere in the full strip.
 */
#define BLINK_MAX_LEDS   512
#define BLINK_MAP_BYTES  (BLINK_MAX_LEDS / 8)
#define MAX_SPARKLES     8

static uint8_t  blink_map[BLINK_MAP_BYTES];
static uint16_t sparkle_led[MAX_SPARKLES];
static uint8_t  sparkle_fade[MAX_SPARKLES];   /* 0 = slot inactive/available */

/* ------------------------------------------------------------------ */
/* Utilities                                                            */
/* ------------------------------------------------------------------ */

/*
 * Convert hue (0-255) to RGB using a 6-segment piecewise approximation.
 * No division, no floats. Outputs are in WS2812 wire order: *g, *r, *b.
 */
static void hue_to_rgb(uint8_t hue, uint8_t *g, uint8_t *r, uint8_t *b)
{
    uint8_t seg, frac, t, q;

    if      (hue <  43) { seg = 0; frac = hue; }
    else if (hue <  86) { seg = 1; frac = hue -  43; }
    else if (hue < 129) { seg = 2; frac = hue -  86; }
    else if (hue < 172) { seg = 3; frac = hue - 129; }
    else if (hue < 215) { seg = 4; frac = hue - 172; }
    else                { seg = 5; frac = hue - 215; }

    t = (frac << 2) + (frac << 1); /* frac * 6, max 252 */
    q = 255 - t;

    switch (seg) {
        case 0: *r = 255; *g = t;   *b = 0;   break; /* red -> yellow   */
        case 1: *r = q;   *g = 255; *b = 0;   break; /* yellow -> green */
        case 2: *r = 0;   *g = 255; *b = t;   break; /* green -> cyan   */
        case 3: *r = 0;   *g = q;   *b = 255; break; /* cyan -> blue    */
        case 4: *r = t;   *g = 0;   *b = 255; break; /* blue -> magenta */
        default:*r = 255; *g = 0;   *b = q;   break; /* magenta -> red  */
    }
}

/* 16-bit Galois LFSR, taps 16/14/13/11 (mask 0xB400), period 65535. Seed must
 * never be 0 — an all-zero state is a fixed point and never advances. */
static uint16_t lfsr_tick(uint16_t v)
{
    uint16_t lsb = v & 1;
    v >>= 1;
    if (lsb)
        v ^= 0xB400;
    return v;
}

/* ------------------------------------------------------------------ */
/* Public API                                                           */
/* ------------------------------------------------------------------ */

void pat_init(struct pat_state *s)
{
    uint8_t i;

    s->pos  = 0;
    s->tick = 0;
    s->lfsr = 1;

    for (i = 0; i < BLINK_MAP_BYTES; i++)
        blink_map[i] = 0;
    for (i = 0; i < MAX_SPARKLES; i++)
        sparkle_fade[i] = 0;
}

uint8_t pat_is_animated(uint8_t pattern)
{
    return (pattern != PAT_OFF && pattern != PAT_SOLID);
}

uint8_t pat_tick(struct pat_state *s, uint16_t n)
{
    uint8_t speed = REG_SPEED ? REG_SPEED : 1;

    if (++s->tick < speed)
        return 0;
    s->tick = 0;
    s->pos++;

    if (n == 0)
        n = 1;

    if (REG_PATTERN == PAT_RETRO_BLINK) {
        uint8_t count = REG_PARAM1 ? REG_PARAM1 : 1;
        uint16_t limit = (n < BLINK_MAX_LEDS) ? n : BLINK_MAX_LEDS;
        uint8_t c;
        if (count > 8) count = 8;
        for (c = 0; c < count; c++) {
            uint16_t idx;
            s->lfsr = lfsr_tick(s->lfsr);
            idx = s->lfsr % limit;
            blink_map[idx >> 3] ^= (uint8_t)(1 << (idx & 7));
        }
    } else if (REG_PATTERN == PAT_TWINKLE) {
        uint8_t density = REG_PARAM1 ? REG_PARAM1 : 1;
        uint8_t k;
        if (density > MAX_SPARKLES) density = MAX_SPARKLES;
        for (k = 0; k < MAX_SPARKLES; k++) {
            if (k >= density) {
                sparkle_fade[k] = 0;
            } else if (sparkle_fade[k] == 0) {
                s->lfsr = lfsr_tick(s->lfsr);
                sparkle_led[k] = s->lfsr % n;
                sparkle_fade[k] = 7;
            } else {
                sparkle_fade[k]--;
            }
        }
    }

    return 1;
}

void pat_prep(struct pat_state *s, uint16_t n)
{
    if (n == 0)
        n = 1;

    s_phase = (uint8_t)(s->pos & 1);

    switch (REG_PATTERN) {
    case PAT_CHASE:
        s_head = s->pos % n;
        break;
    case PAT_WIPE:
        s_wpos = s->pos % (uint16_t)(n + n);
        break;
    case PAT_LARSON: {
        uint16_t span  = (n > 1) ? (n - 1) : 1;
        uint16_t cycle = span + span;
        uint16_t p     = s->pos % cycle;
        s_eye = (p <= span) ? p : (cycle - p);
        break;
    }
    case PAT_RAINBOW:
        s_hue = (uint8_t)s->pos;
        break;
    case PAT_RAINBOW_MTX:
        s_col = 0;
        s_row = 0;
        break;
    default:
        break;
    }
}
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

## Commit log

2026-06-06 Add NeoPixel pattern engine with colour palettes and hardware support
    - 10 animation patterns: solid, chase, blink, alternate, wipe, twinkle,
    rainbow, rainbow-matrix (8x8), retro-blink (50s computer effect)
    - 7 predefined colour palettes in PROGMEM (fire, ocean, forest, party,
    mono-white, rainbow, heat); selected via PAL_SEL register
    - Integer-only math throughout: hue_to_rgb uses piecewise linear
    segments with bit-shifts; LFSR replaces rand() for random patterns
    - Extended I2C register map: PATTERN, SPEED, N_LEDS, SEC colour,
    PARAM1, PAL_SEL; LED array offset moved to 0x0C
    - N_LEDS raised to 64 to cover 8x8 matrix; RAM usage 225/512 bytes
    - PB1 heartbeat LED: 1 Hz blink via Timer0 I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
    [main.c, patterns.c]
2026-06-06 Add MicroPython I2C register test tool
    Interactive CLI for verifying all ATtiny85 firmware registers over I2C.
    Automated tests cover: scan, reset defaults, register read/write, LED
    array block write, CTRL bit fields, all pattern IDs, speed boundaries,
    and all 7 predefined palette colour loads. Live control commands let
    you set pattern, palette, primary/secondary colour, individual LEDs,
    speed, N_LEDS, PARAM1, and toggle PAT_EN/GLB from the REPL prompt.
    [test_registers.py]
2026-06-06 Make test tool run on both MicroPython and Raspberry Pi Linux
    Adds a two-adapter I2C layer: _MicroPythonAdapter (machine.I2C) and
    _LinuxAdapter (smbus2 / /dev/i2c-1), selected automatically by
    detecting whether the machine module is importable. sleep_ms() is
    also abstracted for the same reason. All tests and CLI are unchanged.
2026-06-06 Rewrite README for Space Unicorn firmware
    Documents pin map, build instructions, full register map, all 10
    patterns, predefined palettes, heartbeat LED, testing tool, and RAM
    budget. Acknowledges Brian Starkey (usedbytes), Eric B. Weddington,
    Jörg Wunsch, Elliot Williams, and cpldcpu. Original upstream README
    preserved verbatim at the end of the document.
2026-06-06 Fix WIPE pattern uint8_t overflow at n=128
    cycle = n + n overflowed to 0 when n=128, causing division by zero
    in the modulo. Widened cycle to uint16_t.
    [patterns.c]
2026-06-06 Switch programmer to Atmel-ICE ISP
2026-06-06 Fix ValueError when _check receives list values in block write test
    [test_registers.py]
2026-06-07 Fix user button unresponsive in standalone and no-colour modes
    swirly() only exited on I2C write+stop, so without the I2C master
    the main loop (and button check) was never reached. Also exit on
    btn_event so the button works standalone.
    When the button cycles a pattern and GLB colour is still all-zero
    (no I2C master has set it), fall back to init_color so patterns
    are visible rather than running invisibly in black.
    [main.c]
2026-06-07 README: document fuse requirement for fresh chips
    Add a prominent warning that ATtiny85 ships with CKDIV8 enabled
    (1 MHz), which causes solid-white NeoPixels and an unresponsive
    button. make fuses must be run once on any new or replacement chip.
    Also update default programmer (USBasp → Atmel-ICE) and flash size
    (2772 → 2890 B).
2026-06-22 README: add project links and fix clone URL
    Add a "Project links" section (QR landing page) pointing to the Tildagon
    control app, this firmware/PCB repo, and the EMF hexpansion registry entry
    (0x1969/0x5355). Fix the placeholder clone URL in the build steps.
2026-06-22 Add KiCad hardware design under hardware/
    Publish the Space Unicorn PCB: schematic, board, project-local footprint
    libraries, gerbers/drills and renders. Add a hardware/README and KiCad ignore
    rules; link the design from the main README (Project links + Hardware section).
    Excludes editor history and KiCad backups/local state.
    [hexpansion-B_Cu.gbl, hexpansion-B_Mask.gbs, hexpansion-B_Paste.gbp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]
2026-06-22 README: add v6 front/rear renders to the landing page
2026-06-23 README: project-level title; fix I2C pull-ups to 10k (matches BOM)
2026-06-24 Update i2c/ws2812 submodules: ignore build artifacts
2026-06-29 hardware: update PCB, schematic and gerbers
    Sync the revised KiCad board and schematic and the regenerated gerber set
    from the latest design.
    [hexpansion-B_Cu.gbl, hexpansion-B_Mask.gbs, hexpansion-B_Paste.gbp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]
2026-07-02 Firmware v2: buffer-free streaming, Larson scanner, EEPROM fallback
    Compute each pixel on the fly as the WS2812 stream is clocked out; there is no
    per-LED RGB frame buffer, so the LED count is limited by power and frame rate
    rather than the ATtiny85's 512 bytes of RAM (3026 B flash / 302 B RAM, versus
    ~425 B RAM at just 128 LEDs in the old buffered design).
    - New 256-byte register map (see i2c submodule): 16-colour user palette,
    4-bit packed index buffer for direct/matrix output, 16-bit LED count, N_COLS.
    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
2026-07-04 Firmware v2 fixes: random Retro Blink/Twinkle, index-0 blank, reproducible submodule
    - Retro Blink and Twinkle now use a real 16-bit Galois LFSR with small
    persistent state (per-LED blink bitmap; independently-timed sparkle slots)
    so both read as genuinely random and time-varying, rather than a static
    function of LED index.
    - Index 0 in the packed index buffer now renders as off, so an unpainted or
    erased matrix reads as a blank canvas matching the control app's editor.
    - pat_tick() takes the LED count (needed to reseed random state); main.c
    shares active_n_leds() between the tick and streaming paths.
    - .gitmodules now points the i2c submodule at Corteil/usi_i2c_slave
    (branch spa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
    [main.c, patterns.c]
